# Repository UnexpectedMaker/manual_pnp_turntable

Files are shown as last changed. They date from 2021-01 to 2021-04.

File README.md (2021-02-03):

# Manual PnP Turntable V3

This Manual PnP Turntable is the latest version of my components storage & assembly turntable I initially designed way back in 2019!

I've been asked for the design files many times since I first showed it off in one of my videos, but the V2 version was just a terrible design from a construction stand point, and I always promised I'd release a newer version, and well, this is it!

## BETTER LATE THAN NEVER!

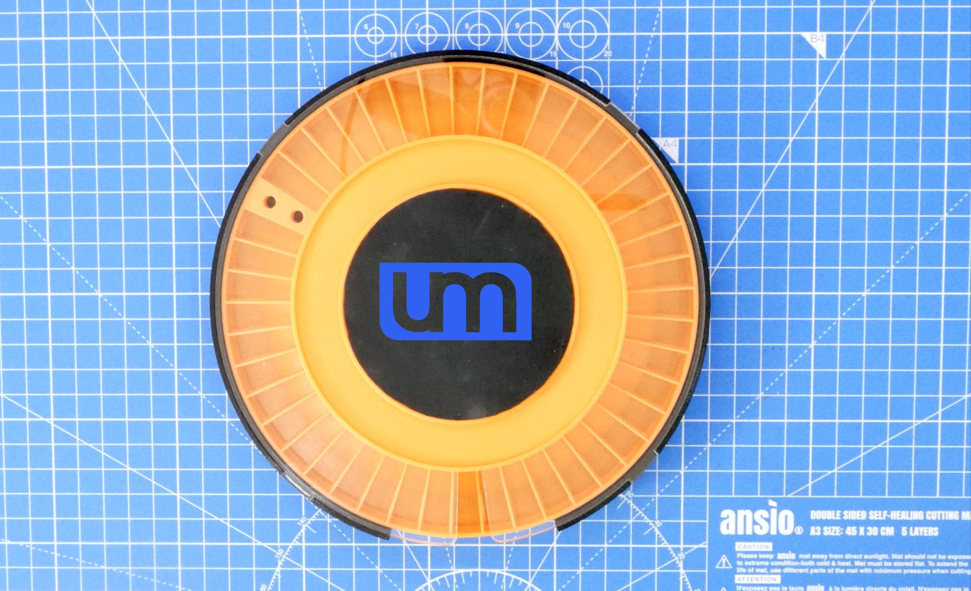
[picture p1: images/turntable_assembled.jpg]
Manual PnP Turntable V2


# Printing The 3D Pieces

### NOTE: The main parts for this turntable require a 3D printer with a print bed of 200mm x 200mm or larger.

There are 3 main 3d printed pieces that make up the turntable, plus some extras.

## turntable_V3_base.stl

- Layer height: 0.2mm
- Brim: Yes
- Supports: None

## turntable_V3_component_tray.stl

- Layer height: 0.2mm
- Brim: Yes
- Supports: Yes, from build plate + bridging

## turntable_V3_assembly_tray.stl

- Layer height: 0.2mm
- Brim: No
- Supports: Yes, from build plate + bridging

## The rest of the files

- Layer height: 0.2mm
- Brim: No
- Supports: None

# Laser cutting or printing the component cover

The component tray cover file is turntable_V3_cover_lasercut.dxf and should be cut out of 3mm thick acrylic, preferably clear, but frosted could also look good. Something transparent so you can see the components and labels inside.

If you can't get access to a laser cutter, you can 3d print the cover by printing turntable_V3_cover_3dprint.stl

# Bearings

These are the bearings I use on the turntable:

6805N Nylon (25x37x6mm)
https://s.click.aliexpress.com/e/_Am2lJV

Smaller (8x22x7mm)
https://s.click.aliexpress.com/e/_9AlN6x

# Assembly Instructions...

I made a video about the turntable and how to assemble it:
(http://www.youtube.com/watch?v=scHSrFdWn5k "Assembly Instructions")

I hope you enjoy making and using this design. If you do, please contact me and let me know you made one and maybe send me a pic!

Cheers :)

# Support Unexpected Maker

I love designing, making and releasing my projects as open source. I do it because I believe it’s important to share knowledge and give back to the community, like many have done before me. It helps us all learn and grow.

That said, a lot of time, effort and finances have gone into designing and releasing these files, so please consider supporting me by buying some of my products:

https://unexpectedmaker.com/shop

https://www.tindie.com/stores/seonr/

Or by becoming a Patron:

https://www.patreon.com/unexpectedmaker

# Join my discord server
https://discord.com/invite/xAHpApP

# Unexpected Maker
https://unexpectedmaker.com

http://youtube.com/unexpectedmaker

http://twitter.com/unexpectedmaker

https://www.facebook.com/unexpectedmaker/

https://www.instagram.com/unexpectedmaker/

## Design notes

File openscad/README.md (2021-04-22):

# Openscad designs for Manual PnP Turntable V3

This is parametric design for Manual PnP Turntable V3 with openscad files that should be easy to modify for various parameters (bearing height, diameter, parts thickness etc). 
As it is it should be fully compatible and other designs unless I made some mistakes.

# Diffeerences from original design

- turntable_base_7mm.stl 
 
New base for bearing 6805-ZZ 25x37x7mm which is cheaper on Amazon on US than original but it 1mm thicker. All other parts remain the same.

I do not like to loose a lot material for support so I created different design for parts tray. It consists of 2 parts A and B and they are glued together. 
Part B has 2 variants - with hole for bearing access and without one. Print only one part B you prefer. Part A stays the same.

- turntable_parts_tray_partA.stl
- turntable_parts_tray_partB_hole.stl
- rntable_parts_tray_partB_nohole.stl

Enjoy.

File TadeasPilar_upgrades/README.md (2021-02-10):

# Manual PNP turntable
## Improvements by [Tadeáš Pilař](https://github.com/TadeasPilar/)

This is my spin at improving the Manual PNP turntable by [Seon aka the Unexpected Maker](https://github.com/UnexpectedMaker)
Made to solve my personal needs in the limited time I had to play with this. Feel free to critisize, redo, or outright refuse my ideas :D

This is compilation of several unrelated changes to the original design. Each of them can be used separatly or all together.
List below lists all the improvments and parts you will have to reprint. Parts I don't mention are same as in the original design.
Images below this list.

They are:
  * Lock ring to hold the plexi in place
    No need to glue or tape the plexiglass. 
    You will need to print new [turntable base](stl/turntable_base.stl) and [lock ring](stl/turntable_lock_ring.stl).
    Held in by several M3x5 self-tapped machine screws(the flat head type). 
    There are holes for 7 screws, but I find 3 are enough.

  * Component tray with joined compartments
    Do you have bigger smd parts to store? No problem.
    Use [new component tray](stl/turntable_component_tray_joined_compartments.stl)  with several compartments joined together.
    Or [this one](stl/turntable_component_tray_joined_compartments_reverse.stl) with inner slopes reversed for some reason...
    Expect more wariants of this to appear in the future.
    
  * No ball bearings - no problem!!!
    [3D printable rings](stl/turntable_bearings.stl) to replace ball bearings.
    Not as smoothm, but definitely usable.
    Beware of limitations of plastic slip bearings. They will not last! But definitely good enough while you wait for real ballbearings to arrive.
    
  * Easy tape fill funnel
    [Funnel variant](stl/turntable_funnel_12x2mm_tape.stl) made for easy filling from tape. 
    Pull tape through(upside down), then using tweezers, loop cover tape back throug the lower hole.
    Now, just pull on the tape and watch your parts neatly pour to your selected compartment.
    WARNING!!! Pulling the cover tape through is real pain in the ass. Only realy worth it if you have lot of parts to get out of the tape. 

## Yay Images   

### New base and lock ring
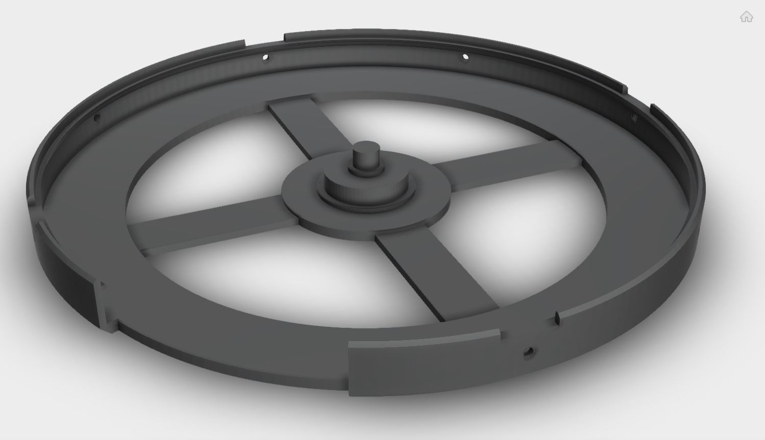
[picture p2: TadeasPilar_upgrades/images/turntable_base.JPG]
Base

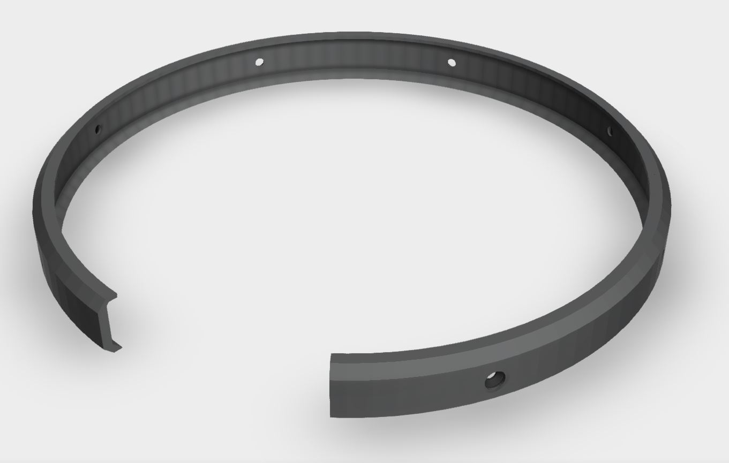
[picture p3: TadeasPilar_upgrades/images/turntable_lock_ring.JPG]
Lock ring


### Components tray with bigger compartments.
Choose your prefered slope direction.<br>
Normal:<br>
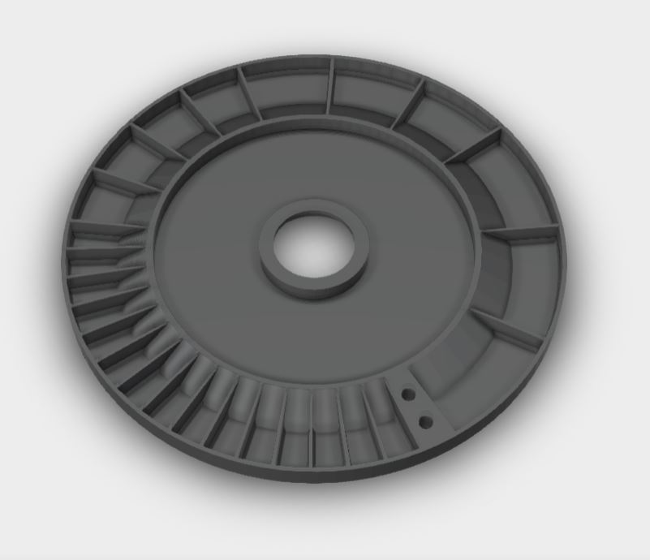
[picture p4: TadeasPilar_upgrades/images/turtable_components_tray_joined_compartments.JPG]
Components tray
<br>
Reversed:<br>
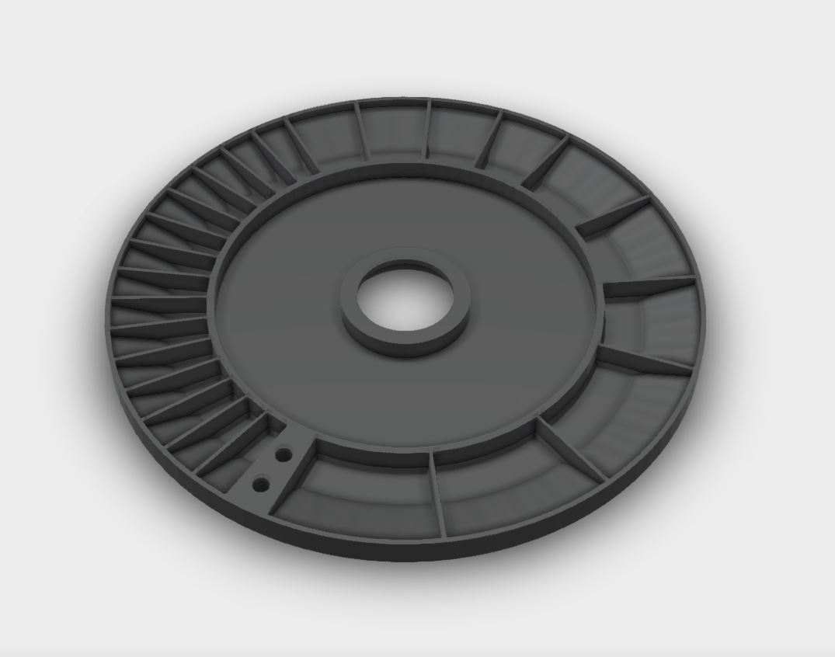
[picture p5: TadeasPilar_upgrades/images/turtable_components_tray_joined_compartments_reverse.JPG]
Components tray


### Plastic bearings
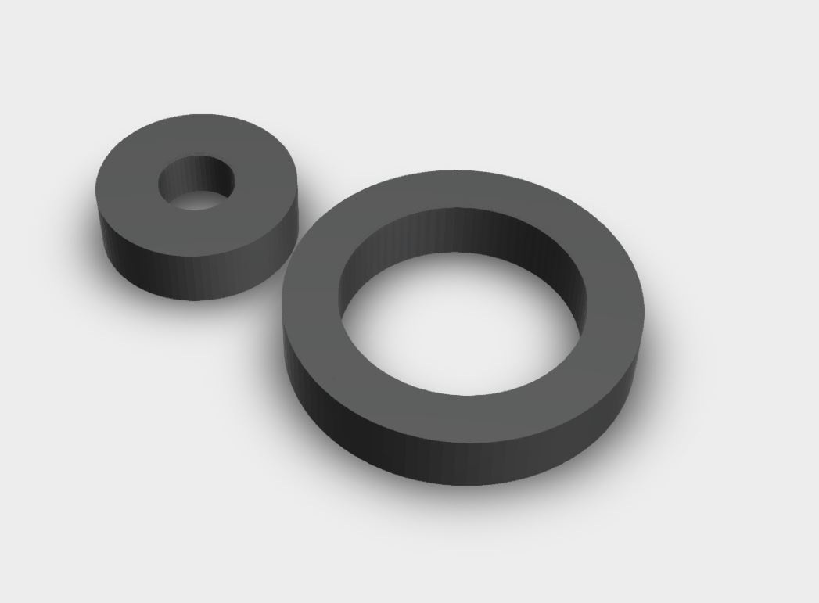
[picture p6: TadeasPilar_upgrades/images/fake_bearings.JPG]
Plastic bearings


## Easy fill funnel
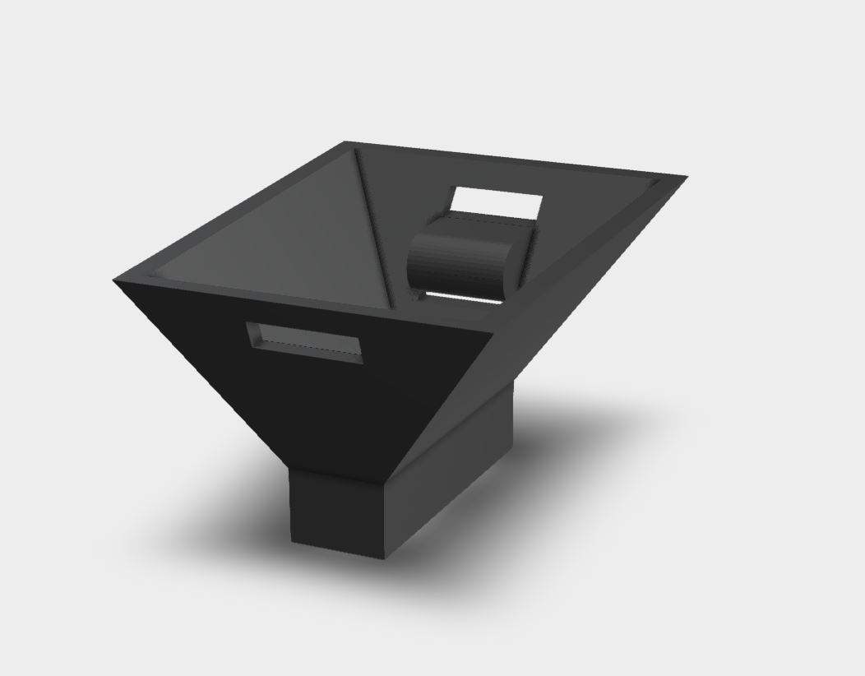
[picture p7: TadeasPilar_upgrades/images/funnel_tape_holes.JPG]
Funnel


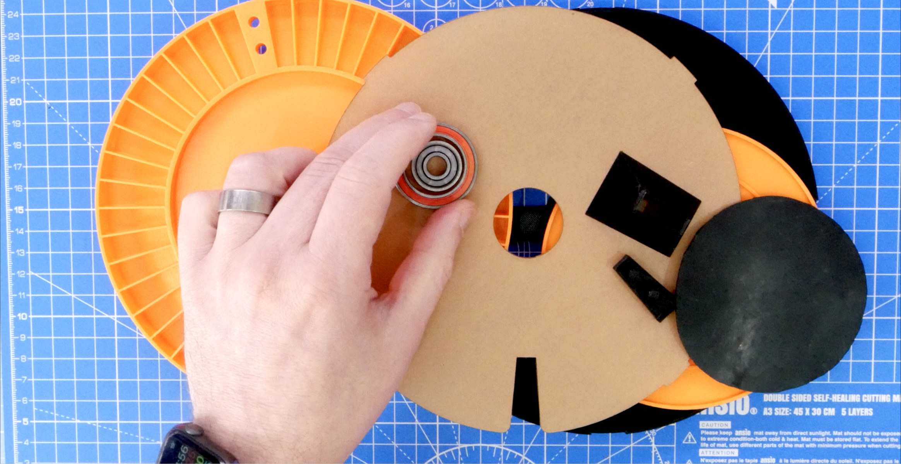
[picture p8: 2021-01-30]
images/turntable_pieces.jpg

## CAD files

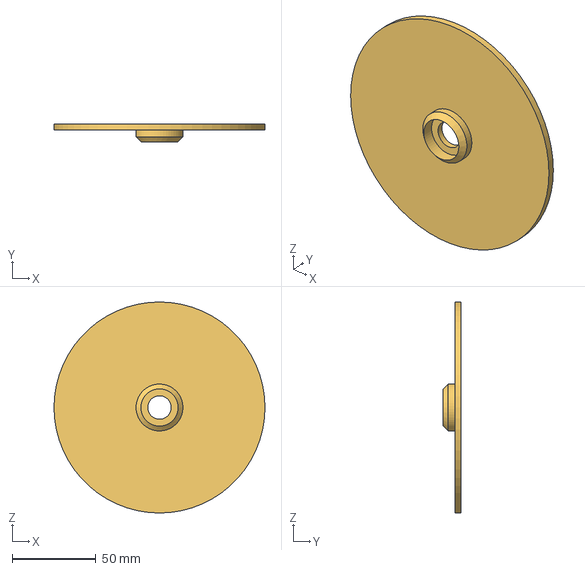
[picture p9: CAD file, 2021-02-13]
step/turntable_V3_assembly_tray.step
126.0 x 10.5 x 126.0 mm

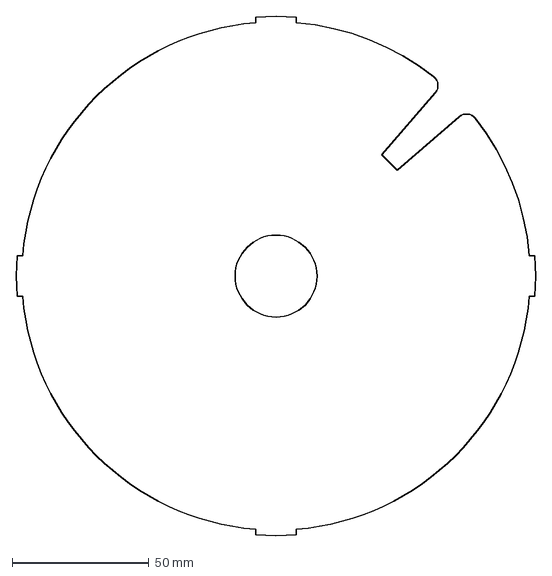
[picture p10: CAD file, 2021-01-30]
dxf/turntable_V3_cover_lasercut.dxf
190.2 x 190.2 mm

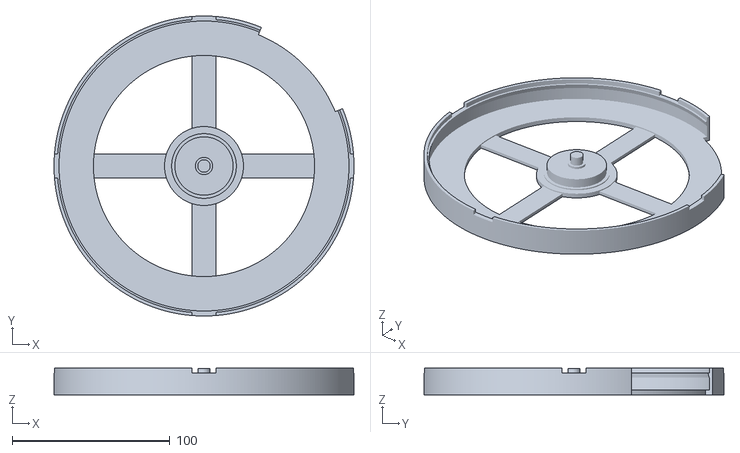
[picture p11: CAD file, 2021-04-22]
openscad/turntable_base_7mm.stl
190.0 x 190.0 x 17.0

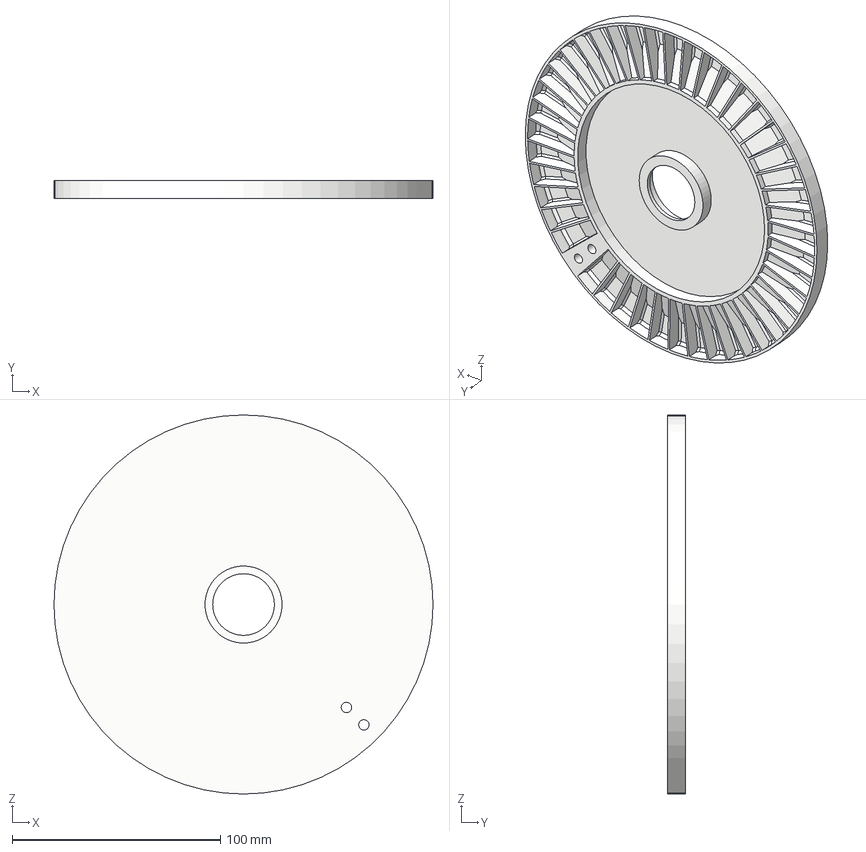
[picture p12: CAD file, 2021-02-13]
step/turntable_V3_component_tray.step
182.0 x 8.60 x 182.0 mm

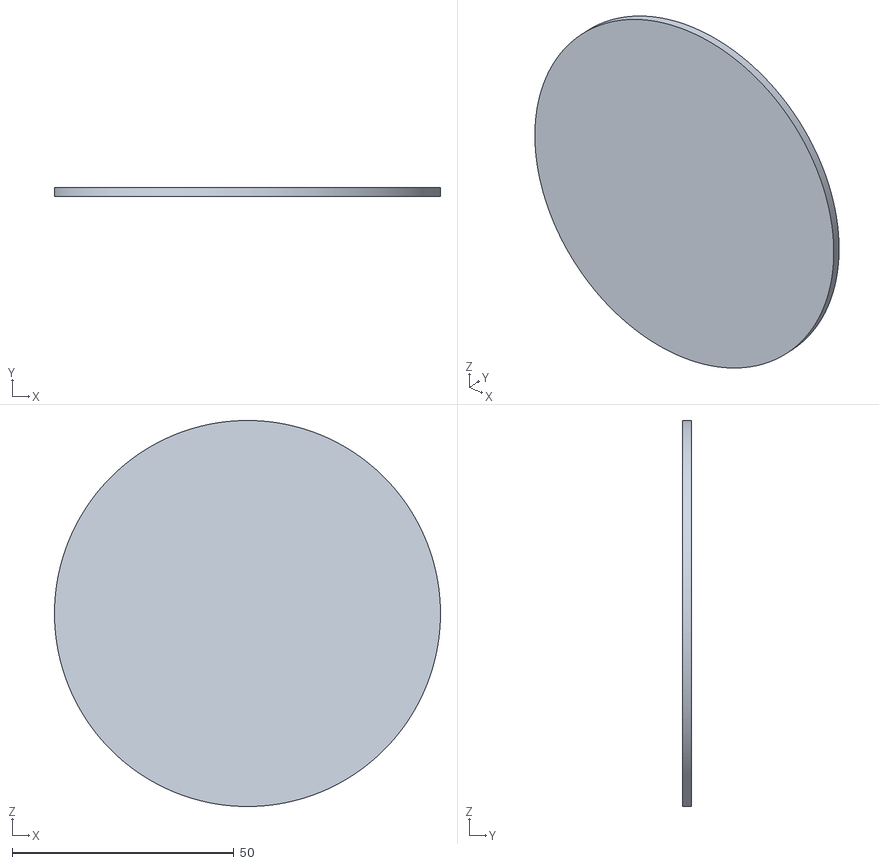
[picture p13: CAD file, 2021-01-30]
stl/turntable_V3_rubber_cutter.stl
87.0 x 2.00 x 87.0

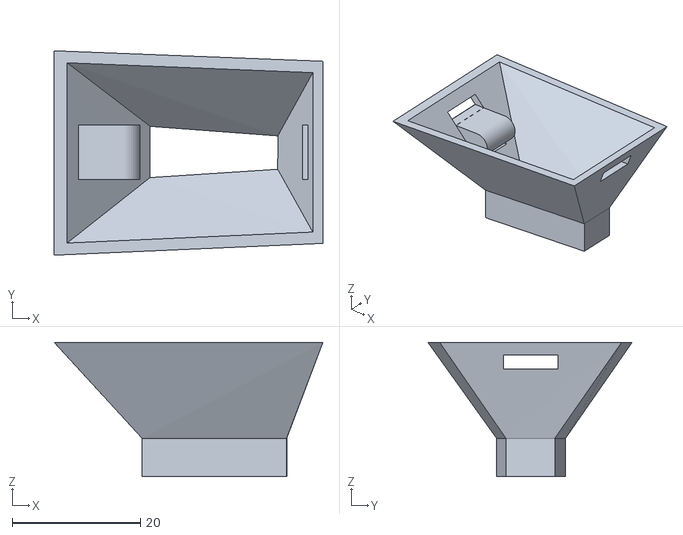
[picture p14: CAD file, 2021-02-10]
TadeasPilar_upgrades/stl/turntable_funnel_12x2mm_tape.stl
42.0 x 31.9 x 21.0

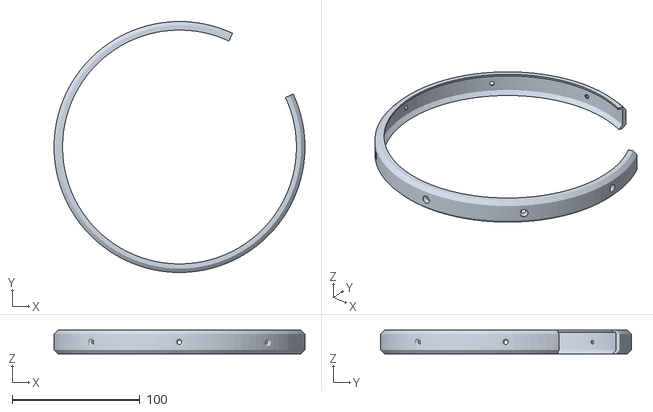
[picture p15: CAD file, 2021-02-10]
TadeasPilar_upgrades/stl/turntable_lock_ring.stl
196.4 x 196.4 x 18.5

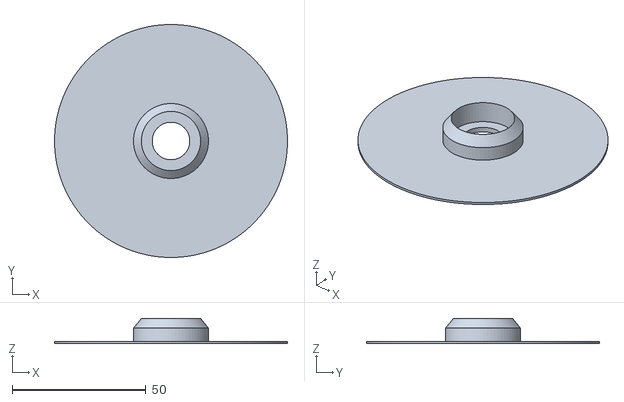
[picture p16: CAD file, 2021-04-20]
openscad/turntable_parts_tray_partB_hole.stl
87.0 x 87.0 x 9.43

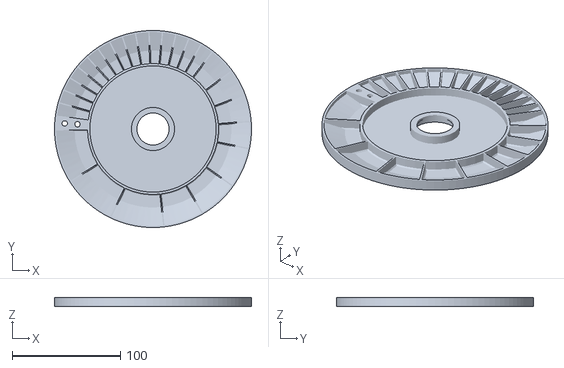
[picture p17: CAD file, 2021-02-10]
TadeasPilar_upgrades/stl/turntable_component_tray_joined_compartments_reverse.stl
182.0 x 182.0 x 8.60

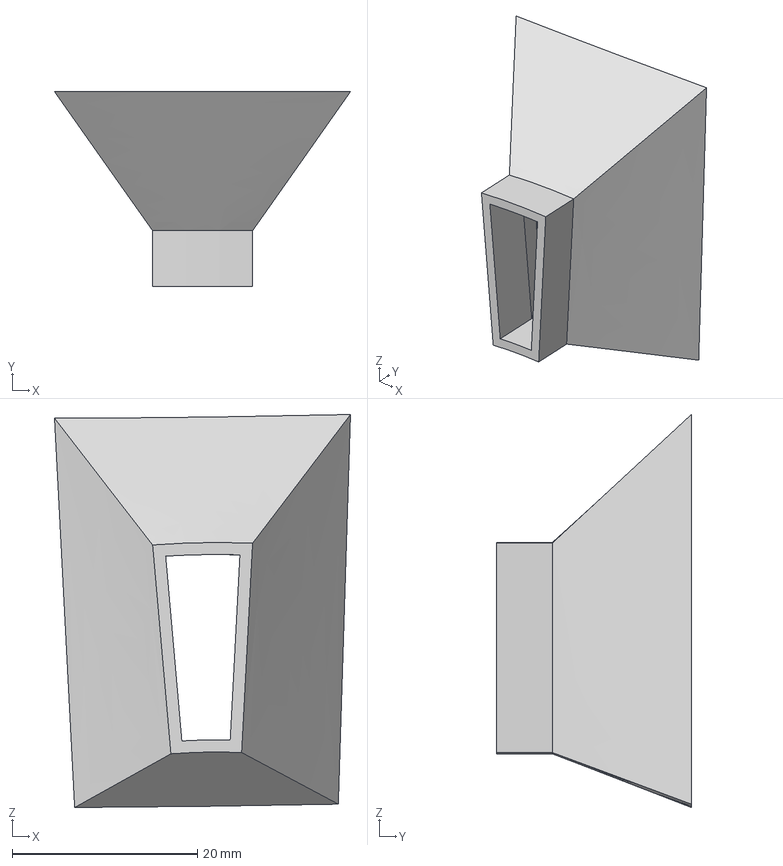
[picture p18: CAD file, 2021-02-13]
step/turntable_V3_funnel.step
31.9 x 21.0 x 42.4 mm

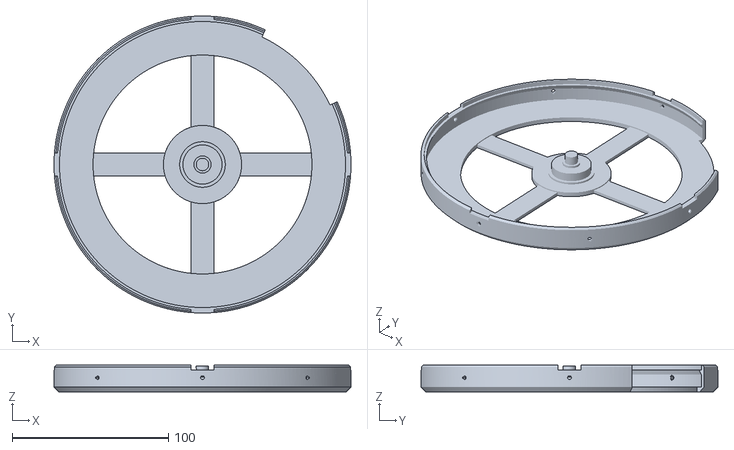
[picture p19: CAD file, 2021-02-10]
TadeasPilar_upgrades/stl/turntable_base.stl
190.0 x 190.0 x 17.0

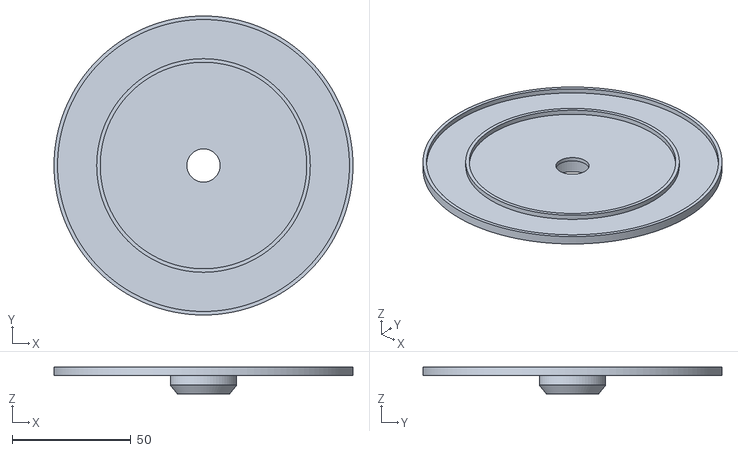
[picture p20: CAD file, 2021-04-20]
openscad/turntable_parts_tray_hole.stl
126.0 x 126.0 x 11.2

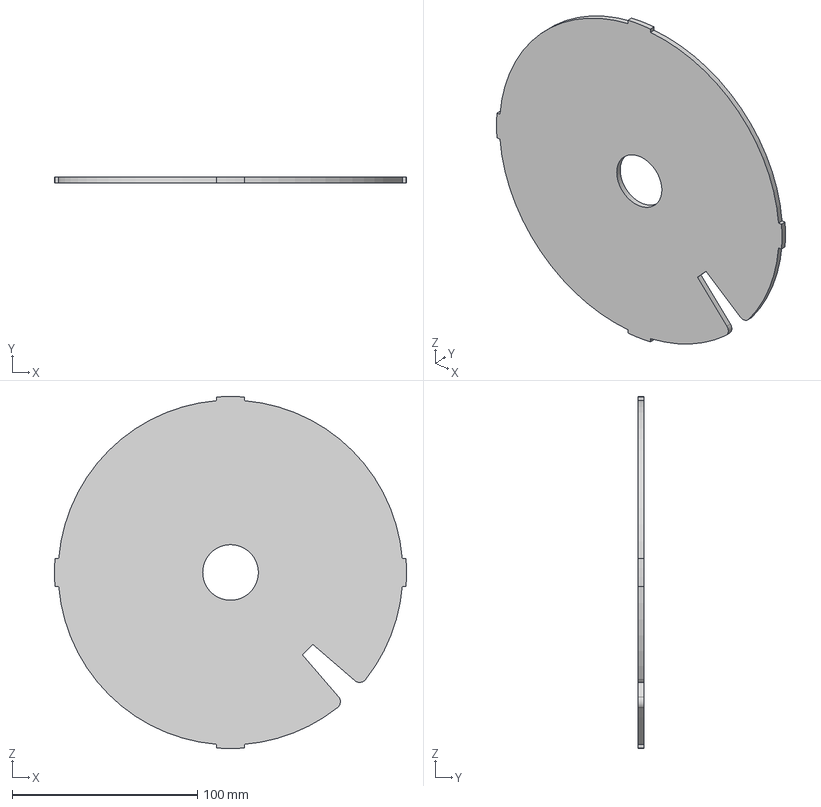
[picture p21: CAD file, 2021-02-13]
step/turntable_V3_cover_3dprint.step
189.9 x 3.00 x 189.9 mm

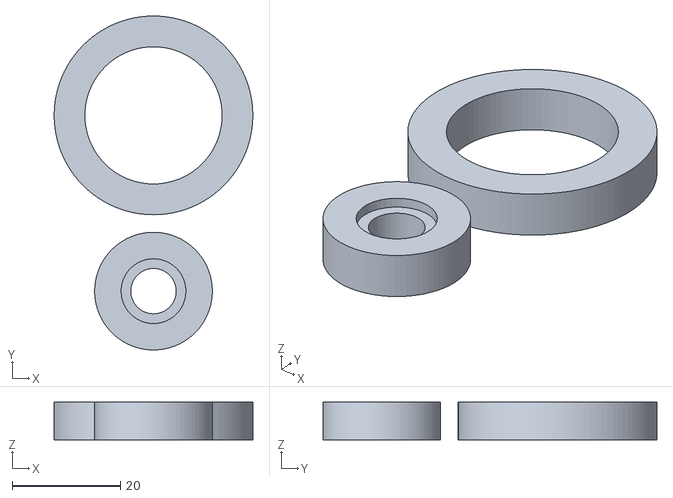
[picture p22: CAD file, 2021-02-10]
TadeasPilar_upgrades/stl/turntable_bearings.stl
36.8 x 61.8 x 7.00

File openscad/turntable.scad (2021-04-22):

tolerance = 0.05;

component_tray_dia = 182;
component_tray_height = 8.6;
component_tray_inner_idia = 39.8;
component_tray_inner_odia = 116.6;
component_tray_inner_thk = 2;
component_tray_hole_dia = 29.6;
component_tray_stopper_hole_dia=5;

component_pocket_idia = 121;
component_pocket_odia = 179;
component_pocket_length = 29;
component_pocket_depth = 8.1;
component_pocket_angle = 8;

component_bearing_idia = 25;
component_bearing_odia = 37;
component_bearing_height = 6;

parts_outer_dia = 126;
parts_inner_dia = 90;
parts_border = 3;
parts_hole_dia = 14;
parts_thk = 1.6;
parts_border_thk = 2;
parts_bearing_holder_dia = 28;
parts_bearing_holder_height = 4;
parts_bearing_holder_thk = 3.20;

part_bearing_idia = 8;
part_bearing_odia = 22;
part_bearing_height = 7;

base_height = 17;
base_outer_dia = component_tray_dia + 8;
base_outerloop_odia = component_tray_dia + 4;
base_outerloop_idia = base_outerloop_odia - 46;
base_sector_angle = 45;

cover_something_width = 15;
cover_thk = 3;

base_innerloop_odia = 50;
base_outerloop_thk = 3;
base_innerloop_thk = base_outerloop_thk;

module sector(h, d, a1, a2) {
    if (a2 - a1 > 180) {
        difference() {
            cylinder(h=h, d=d,$fn=256);
            translate([0,0,-0.5]) sector(h+1, d+1, a2-360, a1); 
        }
    } else {
        difference() {
            cylinder(h=h, d=d,$fn=256);
            rotate([0,0,a1]) translate([-d/2, -d/2, -0.5])
                cube([d, d/2, h+1]);
            rotate([0,0,a2]) translate([-d/2, 0, -0.5])
                cube([d, d/2, h+1]);
        }
    }
}    

module base() {
    difference() {
        union() {
            cylinder( d=base_innerloop_odia, h=base_innerloop_thk, $fn=128 );
            for( a=[0:90:360] )
                rotate([0,0,a] )
                    translate([0,base_outerloop_idia/4 + base_innerloop_odia/4,1.1])
                        cube( size=[15,(base_outerloop_idia - base_innerloop_odia)/2 + 4,2.2],center=true );

            difference() {
                cylinder( d=base_outerloop_odia+1, h=base_innerloop_thk, $fn=256 );
                translate([0,0,-1])
                cylinder( d=base_outerloop_idia, h=base_innerloop_thk+2, $fn=256 );
            }

            difference() {
                cylinder( d=base_outer_dia, h=base_height, $fn=256 );
                translate([0,0,base_height-cover_thk])
                   cylinder( d=base_outerloop_odia, h=cover_thk+2, $fn=256 );
                translate([0,0,base_height-cover_thk-4])
                    cylinder( d2=component_tray_dia+1,d1=base_outerloop_odia,h=5,$fn=256 );
                translate([0,0,-1])
                   cylinder( d=base_outerloop_odia, h=base_height-cover_thk-2, $fn=256 );
                for( a=[0:90:360] )
                    rotate([0,0,a] )
                        translate([0,base_outer_dia/4+base_outerloop_odia/4,base_height-cover_thk/2+1])
                        cube( size=[cover_something_width,(base_outer_dia-base_outerloop_odia)/2+4,cover_thk+2],center=true );
            }
            
            cylinder( d=component_bearing_odia+4,h=base_innerloop_thk+7.8-component_bearing_height,$fn=64 );
            cylinder( d=component_bearing_odia-2*tolerance,h=base_innerloop_thk+6.6,$fn=128 );
            cylinder( d=part_bearing_idia+3,h=base_innerloop_thk+15-part_bearing_height,$fn=64 );
            cylinder( d=part_bearing_idia-2*tolerance,h=base_innerloop_thk+13.6,$fn=64 );
        }

        difference() {
            translate([0,0,-1])
            sector( base_height+2,    base_outer_dia+4,(90-base_sector_angle)/2,(90+base_sector_angle)/2);
            translate([0,0,-2])
            sector( base_height+4,    base_outer_dia-10,(90-base_sector_angle)/2-10,(90+base_sector_angle)/2+10);
        }
    }
}

module component_pocket()
{
    hull() {
        difference() {
            translate( [0,(component_pocket_length-component_pocket_odia)/2,component_pocket_depth-4.2] )
                cylinder( d=component_pocket_odia,h=4.2,$fn=256 );
            translate( [0,(-component_pocket_idia-component_pocket_length)/2,component_pocket_depth-5.2] )
                cylinder( d=component_pocket_idia,h=6.2,$fn=256 );
            for( i=[-1,1] ) 
                translate([i*component_pocket_odia/2,-component_pocket_odia/2,0]) 
                    rotate( [0,0,-i*4] )
                        cube( size=[component_pocket_odia, component_pocket_odia*2, component_pocket_depth*2 + 4], center=true );
            
        }
        difference() {
            translate( [0,7,0.5] )
                cube( size=[20,10.7,1],center=true );
            for( i=[-1,1] ) 
                translate([i*component_pocket_odia/2,-component_pocket_odia/2,0]) 
                    rotate( [0,0,-i*3] )
                        cube( size=[component_pocket_odia, component_pocket_odia*2, 2*(component_pocket_depth-4.2 )], center=true );
        }
    }
}

module component_tray()
{
    difference() {
        cylinder( d=component_tray_dia, h=component_tray_height, $fn=256 );
        difference() {
            translate( [0,0,component_tray_inner_thk] )
                cylinder( d=component_tray_inner_odia, h=component_tray_height, $fn=128 );
            cylinder( d=component_tray_inner_idia, h=component_tray_height+component_tray_inner_thk+2, $fn=128 );
        }
        translate( [0,0,-1] )
            cylinder( d=component_tray_hole_dia, h=component_tray_height+2, $fn=64 );
        translate( [0,0,-2] )
            cylinder( d=component_bearing_odia+2*tolerance, h=component_tray_height, $fn=64 );
        translate( [0,70,-1] )
            cylinder( d=component_tray_stopper_hole_dia, h=component_tray_height+2, $fn=32 );
        translate( [0,81.7,-1] )
            cylinder( d=component_tray_stopper_hole_dia, h=component_tray_height+2, $fn=32 );
        for( a=[10:10:350] ) 
            rotate( [0,0,a] )
                translate( [0,(component_pocket_idia+component_pocket_odia)/4,component_tray_inner_thk] )
                    component_pocket();
            
        
    }
}

/*
     part 1 - single parts tray
          2 - two modules maint part
          3 - two modeles bearing part
*/

module parts_tray(hole=1,part=1)
{
    difference() {
        union() {
            if( part != 3 )
                cylinder( d=parts_outer_dia, h=parts_thk+parts_border_thk,$fn=128 );
            else 
                cylinder( d=parts_inner_dia-parts_border, h=parts_thk/2,$fn=128 );
                
            if( part != 2 ) {
                holder_height = parts_bearing_holder_height + ( part == 3 ? parts_border_thk / 2:0);
                translate( [0,0,-holder_height] )
                    cylinder( d=parts_bearing_holder_dia, h=holder_height,$fn=64 );
                translate( [0,0,-holder_height-4] )
                    cylinder( d2=parts_bearing_holder_dia, d1=part_bearing_odia-0.5, h=4,$fn=64 );
            }
        }
        if( part == 2 )
            translate( [0,0,-1] )
                cylinder( d=parts_bearing_holder_dia, h=parts_thk+2,$fn=64 );
            
        difference() {
            translate( [0,0,parts_thk] )
                cylinder( d=parts_outer_dia-parts_border, h=parts_thk+parts_border_thk,$fn=128 );
            translate( [0,0,parts_thk-1] )
                cylinder( d=parts_inner_dia, h=parts_thk+parts_border_thk+2,$fn=128 );
        }
        translate( [0,0,parts_thk - (part!=2 ? 0 : parts_thk/2)] )
            cylinder( d=parts_inner_dia-parts_border, h=parts_thk+parts_border_thk,$fn=128 );
        if( hole ) 
            translate( [0,0,-2] )
                cylinder( d=parts_hole_dia, h=parts_thk+parts_border_thk+4,$fn=128 );

        if( part != 2 ) 
            translate( [0,0,-parts_bearing_holder_height-5-( part == 3 ? parts_border_thk / 2:0)] )
                cylinder( d=part_bearing_odia+2*tolerance, h=5+parts_bearing_holder_height,$fn=64 );

    }
}

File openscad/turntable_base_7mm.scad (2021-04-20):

include <turntable.scad>

component_bearing_height = 7;
base();

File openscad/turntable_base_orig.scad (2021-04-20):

include <turntable.scad>

base();

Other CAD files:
openscad/turntable_base_orig.stl
step/turntable_V3_base.step
openscad/turntable_component_tray.stl
openscad/turntable_parts_tray_partB_nohole.stl
openscad/turntable_component_tray.scad
TadeasPilar_upgrades/stl/turntable_component_tray_joined_compartments.stl
openscad/turntable_parts_tray_hole.scad
openscad/turntable_parts_tray_nohole.scad
openscad/turntable_parts_tray_nohole.stl
openscad/turntable_parts_tray_partA.scad
openscad/turntable_parts_tray_partA.stl
openscad/turntable_parts_tray_partB_hole.scad
openscad/turntable_parts_tray_partB_nohole.scad
step/turntable_V3_rotation_plug.step
stl/turntable_V3_assembly_tray.stl
stl/turntable_V3_base.stl
stl/turntable_V3_component_tray.stl
stl/turntable_V3_cover_3dprint.stl
stl/turntable_V3_funnel.stl
stl/turntable_V3_rotation_plug.stl

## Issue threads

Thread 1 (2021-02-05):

Is is possible to get cad files?

vitormhenrique, 2021-02-05:
This is an awesome design! thanks for sharing!
Would you mind sharing the cad designs for it (step files for example) ? (instead of the STL ones) there are a couple things that I think would be nice, and editing STL's are never too fun...

Thanks!

UnexpectedMaker, 2021-03-07:
Not suer if you noticed but I added STEP files a while ago :)

vitormhenrique, 2021-03-07:
I did! Thank you very much!

Closed 2021-03-07.

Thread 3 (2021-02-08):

Thin bottom component tray, maybe thicken it to 0.8mm?

Squantor, 2021-02-08:
I think the component tray has very thin bottom. When I slice the STL in cura it is only two layers. that is a bit on the thin side. Would it be an idea to make it a bit thicker so it is at least three or four layers? I print mostly in PETG and the white filament I have is a more translucent then really white. A few extra layers would help with the opacity, but this is a problem on my side.

Another thing I have noticed but not related to the STL's is that when I slice the component tray with cura, the tool path in cura differs from what is being printed! Really strange, but this is cura's problem. Cura shows the first layer begin printed as one big surface and then makes the component pockets, but in reality the first layer prints quite different with small component pockets and then printing the walls seperate.

Thanks for making this device public, I am printing everything in steps. Black base, white component tray and gray assembly tray. Just waiting for the bearings.

For these big flat prints, I am really glad I installed an ABL sensor on my printer.

rglory, 2021-04-19:
Actually it would be nice to make it 1mm thicker and on top of that it will work with  6805-ZZ bearing which is math cheaper on Amazon but 1mm thicker.

UnexpectedMaker, 2021-04-19:
> Actually it would be nice to make it 1mm thicker and on top of that it will work with 6805-ZZ bearing which is math cheaper on Amazon but 1mm thicker.

The STL files are available for those that want to modify the design to work with different thickness bearings. I chose these because I wanted the unit as low profile as possible.

rglory, 2021-04-19:
I understand. But cheapest bearing for 25x37x6mm I can find on amazon costs $11.49 ($5.75/Item)  while 25x37x7mm costs $14.97 ($1.50 / Item) - quite some difference for 1mm thickness difference.

UnexpectedMaker, 2021-04-19:
Ok, so you can buy the cheaper one and modify the STL file to suit. Or you can buy the bearings from Aliexpress and pay 1/3 of the price. Either way you have options :)

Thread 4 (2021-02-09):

Base for 4mm plexi?

taposk, 2021-02-09:
Hello!
Is it possible to get a version of the base for 4mm acrylic?
In France we mostly find 4mm plates and not 3mm...
Thanks!!

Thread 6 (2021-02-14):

Tolerances are a little tight

bjonesrock, 2021-02-14:
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

Hey I'm really excited to finish putting this together. I have to wait a month for the bearings. But I printed the parts and laser cut some 3mm acrylic. When I put the parts together I ended up having to file down the tabs on the laser cut acrylic for it to fit together. It would be great if the tolerances were a little looser to account for less than perfect 3D printers and laser cutters

Thanks!
-Ben

bjonesrock, 2021-02-16:
[pnp-3mm-acrylic-v2.zip](https://github.com/UnexpectedMaker/manual_pnp_turntable/files/5986199/pnp-3mm-acrylic-v2.zip)
I scaled down the outside part of the DXF slightly and it's a perfect fit when I cut it with my laser cutter now. I converted it to an SVG in inkscape. I'm attaching the file I used, feel free to use it in your project. Thanks!

Closed 2021-02-16.

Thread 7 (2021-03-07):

Tray scrapes on frame - not enough clearance on bearing

bjonesrock, 2021-03-07:
When the larger bearing is pressed flush into the tray it doesn't have enough clearance on the bottom to spin freely

I think the bottom lip for the large bearing needs to be taller

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

UnexpectedMaker, 2021-03-07:
Mine is pushed 100% as far as I can push it and I don't see that issue. Maybe just a printer tolerance thing?

bjonesrock, 2021-03-07:
It's possible, I had a lot of issues with the filament I used to print this. I don't know why I decided to use something other than Hatchbox.

I didn't buy the larger bearing from Aliexpress, I found an ebay seller that had the same specs:
https://www.ebay.com/itm/10pcs-6805RD-MR25376-61805-6805N-6805-RS-Ball-Bearing-25x37x6mm-HT2-BB51-GCR15/283611747473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

It's possible the inner ring on the bearing you have is taller than mine

I'm going to try printing some shims at different heights and see is that fixes it
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

If that fixes it I'll attach the STL file

bjonesrock, 2021-03-07:
Using a shim with a height of 0.5mm mostly fixed it for me. I think my tray and/or my frame might be slightly warped which is causing the tray to rub on both the acrylic and the frame.

Attached is the STL file. I tried a bunch of different heights. If someone else has this issue later and 0.5mm isn't the right height for you, just scale the STL file on the Z axis to the size you need.

[0.5mm-shim.stl.zip](https://github.com/UnexpectedMaker/manual_pnp_turntable/files/6096545/0.5mm-shim.stl.zip)

Closed 2021-03-07.

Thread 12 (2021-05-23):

License clarification

darigovresearch, 2021-05-23:
This is a great project and thanks for releasing it!

Would be helpful to know what kind of license this project is under CC0 (like the [infidel filament diameter sensor](https://github.com/drspangle/infidel-sensor)), CERN (like the [openflexure 3D printed microscope](https://gitlab.com/openflexure/openflexure-microscope) or TAPR (like the [Glia otoscope](https://github.com/GliaX/Otoscope)) just to name a few. This may encourage people to build on top of your work and also potentially contribute back to the project as well.

Also you mention that you won't be selling it as a product but perhaps someone from the community may wish to do so, having clarification on the license and if it can be used for commercial use would be helpful to know.

Could you please advise?

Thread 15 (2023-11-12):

Idea for clipping lid

Bazmundi, 2023-11-12:
So firstly thanks for releasing this design, it's gold!

Not forgetting good job doing this in OpenSCAD.

Second, I have an idea for clipping the lid down.

So far it looks like this (just a hack at the moment):

```

/* new parameters will need be added to go further */
cover_something_width = 2;
cover_thk = 10;

module base() {
    difference() {
        union() {
            cylinder( d=base_innerloop_odia, h=base_innerloop_thk, $fn=128 );
            for( a=[0:90:360] )
                rotate([0,0,a] )
                    translate([0,base_outerloop_idia/4 + base_innerloop_odia/4,1.1])
                        cube( size=[15,(base_outerloop_idia - base_innerloop_odia)/2 + 4,2.2],center=true );

            difference() {
                cylinder( d=base_outerloop_odia+1, h=base_innerloop_thk, $fn=256 );
                translate([0,0,-1])
                cylinder( d=base_outerloop_idia, h=base_innerloop_thk+2, $fn=256 );
            }

            difference() {
                cylinder( d=base_outer_dia, h=base_height, $fn=256 );
                translate([0,0,base_height-cover_thk])
                   cylinder( d=base_outerloop_odia, h=cover_thk+2, $fn=256 );
                translate([0,0,base_height-cover_thk-4])
                    cylinder( d2=component_tray_dia+1,d1=base_outerloop_odia,h=5,$fn=256 );
                translate([0,0,-1])
                   cylinder( d=base_outerloop_odia, h=base_height-cover_thk-2, $fn=256 );
        
                /* here is the main hack */
                for( a=[0:90:360] ) {
                    rotate([0,0,a-5] )
                        translate([0,base_outer_dia/4+base_outerloop_odia/4,base_height-cover_thk/2+1])
                        cube( size=[cover_something_width,(base_outer_dia-base_outerloop_odia)/2+4,cover_thk+2],center=true );
                    rotate([0,0,a+5] )
                        translate([0,base_outer_dia/4+base_outerloop_odia/4,base_height-cover_thk/2+1])
                        cube( size=[cover_something_width,(base_outer_dia-base_outerloop_odia)/2+4,cover_thk+2],center=true );
                }
            }
    
            cylinder( d=component_bearing_odia+4,h=base_innerloop_thk+7.8-component_bearing_height,$fn=64 );
            cylinder( d=component_bearing_odia-2*tolerance,h=base_innerloop_thk+6.6,$fn=128 );
            cylinder( d=part_bearing_idia+3,h=base_innerloop_thk+15-part_bearing_height,$fn=64 );
            cylinder( d=part_bearing_idia-2*tolerance,h=base_innerloop_thk+13.6,$fn=64 );
        }

        difference() {
            translate([0,0,-1])
            sector( base_height+2,    base_outer_dia+4,(90-base_sector_angle)/2,(90+base_sector_angle)/2);
            translate([0,0,-2])
            sector( base_height+4,    base_outer_dia-10,(90-base_sector_angle)/2-10,(90+base_sector_angle)/2+10);
        }
    }
}
```

It turns out as the outer radius is 180mm, adding or subtracting 5 degrees coincidently gives a cord length of 15mm, centred on the tabs on the lid.

So, next steps are to add a thicker rim where the lid sits and a v-groove.  The tabs on the lid will then need be bevelled.  So 3D print would solve that readily, but it will take a little filing when laser cutting clear perspex etc.

The idea to have the flexture clip hold the lid on.  Probably wants finger nail tabs to help flex the clip etc.

I'll get back to you once I've prototyped this idea.   Unless you want to take the idea and run with?

Bazmundi, 2023-11-12:
Yeah so I ended up with a triangular notch, with ...

```
include <turntable.scad>
sqDia = 3;
sqRad = sqDia/2;

module notch() {
    intersection() {

        for(a = [0:90:360])
            sector(sqDia,base_outerloop_odia+sqDia,a-4.6,a+4.6);

        union(){
            cylinder(sqRad,d1=base_outerloop_odia,d2=base_outerloop_odia+sqRad,$fn=256);
            translate ([0,0,sqRad]) cylinder(sqRad,d1=base_outerloop_odia+sqRad,d2=base_outerloop_odia,$fn=256);
        }
    }
}
```
... and then ...

```
include <turntable.scad>
include <notch.scad>

component_bearing_height = 7;

difference () {
    base();
    translate([0,0,base_height-sqDia]) notch();
}
```
Works a hoot ...
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

Bazmundi, 2023-11-12:
Okay, you got me.  The module notch() needs to be:

```
include <turntable.scad>
sqDia = 3;
sqRad = sqDia/2;

module notch() {
    intersection() {

        difference () {
            for(a = [0:90:360])
                sector(sqDia,base_outerloop_odia+sqDia,a-4.6,a+4.6);
            cylinder( d=base_innerloop_odia, h=base_innerloop_thk, $fn=128 );
        }

        union(){
            cylinder(sqRad,d1=base_outerloop_odia,d2=base_outerloop_odia+sqRad,$fn=256);
            translate ([0,0,sqRad]) cylinder(sqRad,d1=base_outerloop_odia+sqRad,d2=base_outerloop_odia,$fn=256);
        }
    }
}
```

So as not to notch the pillar in the centre.

Bazmundi, 2023-11-12:
Yep, my bad.

```
cover_something_width = 1;
cover_thk = 3;
slot = 10;

module base() {
    union() {

        // add a thicker rim to make room for notch
        for(a = [0:90:360])
            translate([0,0,13])
               difference () {
                   sector(4,base_outerloop_odia+8,a-4.6,a+4.6);
                   sector(4,base_outerloop_odia+4,a-4.6,a+4.6);
               }

        // add a finger notch to assist in inserting the lid
        for(a = [0:90:360])
            translate([0,0,17])
               difference () {
                   sector(2,base_outerloop_odia+8,a-4.6,a+4.6);
                   sector(2,base_outerloop_odia+6,a-4.6,a+4.6);
               }

        difference() {
            union() {
                cylinder( d=base_innerloop_odia, h=base_innerloop_thk, $fn=128 );
                for( a=[0:90:360] )
                    rotate([0,0,a] )
                        translate([0,base_outerloop_idia/4 + base_innerloop_odia/4,1.1])
                            cube( size=[15,(base_outerloop_idia - base_innerloop_odia)/2 + 4,2.2],center=true );

                difference() {
                    cylinder( d=base_outerloop_odia+1, h=base_innerloop_thk, $fn=256 );
                    translate([0,0,-1])
                    cylinder( d=base_outerloop_idia, h=base_innerloop_thk+2, $fn=256 );
                }

                difference() {
                    cylinder( d=base_outer_dia, h=base_height, $fn=256 );
                    translate([0,0,base_height-cover_thk])
                       cylinder( d=base_outerloop_odia, h=cover_thk+2, $fn=256 );
                    translate([0,0,base_height-cover_thk-4])
                        cylinder( d2=component_tray_dia+1,d1=base_outerloop_odia,h=5,$fn=256 );
                    translate([0,0,-1])
                       cylinder( d=base_outerloop_odia, h=base_height-cover_thk-2, $fn=256 );
            
                    // the hack
                    for( a=[0:90:360] ) {
                        rotate([0,0,a-4.9] )
                            translate([0,base_outer_dia/4+base_outerloop_odia/4,base_height-slot/2+1])
                            cube( size=[cover_something_width,(base_outer_dia-base_outerloop_odia)/2+4,slot+2],center=true );
                        rotate([0,0,a+4.9] )
                            translate([0,base_outer_dia/4+base_outerloop_odia/4,base_height-slot/2+1])
                            cube( size=[cover_something_width,(base_outer_dia-base_outerloop_odia)/2+4,slot+2],center=true );
                    }
                }
        
                cylinder( d=component_bearing_odia+4,h=base_innerloop_thk+7.8-component_bearing_height,$fn=64 );
                cylinder( d=component_bearing_odia-2*tolerance,h=base_innerloop_thk+6.6,$fn=128 );
                cylinder( d=part_bearing_idia+3,h=base_innerloop_thk+15-part_bearing_height,$fn=64 );
                cylinder( d=part_bearing_idia-2*tolerance,h=base_innerloop_thk+13.6,$fn=64 );
            }

            difference() {
                translate([0,0,-1])
                sector( base_height+2,    base_outer_dia+4,(90-base_sector_angle)/2,(90+base_sector_angle)/2);
                translate([0,0,-2])
                sector( base_height+4,    base_outer_dia-10,(90-base_sector_angle)/2-10,(90+base_sector_angle)/2+10);
            }
        }
    }
}
```
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

Bazmundi, 2023-11-12:
Played a little and got a final draft that won't need supports.

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

Bazmundi, 2023-11-18:
Nope.  Probably as expected. The clips are too stiff and break off.  But, it occured to use the notch as a catch, and rotate the top into that from a slot, hence the solution at [thingiverse](https://www.thingiverse.com/thing:6310146).

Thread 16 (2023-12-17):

Error in component bearing post dia

Bazmundi, 2023-12-17:
component_bearing_idia is never used.  Line 95 seems to be the problem.

WAS

```
 94           cylinder( d=component_bearing_odia+4,h=base_innerloop_thk+7.8-component_bearing_height,$fn=64 );
 95           cylinder( d=component_bearing_odia-2*tolerance,h=base_innerloop_thk+6.6,$fn=128 );

```
IS

```
 94           cylinder( d=component_bearing_odia+4,h=base_innerloop_thk+7.8-component_bearing_height,$fn=64 );
 95           cylinder( d=component_bearing_idia-2*tolerance,h=base_innerloop_thk+6.6,$fn=128 );

```

A little poking around and my find validates https://github.com/UnexpectedMaker/manual_pnp_turntable/pull/11/files per rglory

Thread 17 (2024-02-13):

dxf for lasercutting is garbled up and has a lot of double lines which causes the slot to be not as smooth as it can be. Here is a fix

DrBabbage, 2024-02-13:
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

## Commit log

2021-01-30 Update README.md
    Added a note about the minimum print bed requirements for printing the 3 main parts.
2021-02-13 Added .step files to make it easier to modify the parts
    [turntable_V3_assembly_tray.step, turntable_V3_base.step, turntable_V3_component_tray.step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]
2021-04-20 Added parametric models using openscad
    [turntable.scad, turntable_base_7mm.scad, turntable_base_7mm.stl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]
2021-04-22 Fixed mistake with base bearing dia for components
    [turntable.scad, turntable_base_7mm.stl, turntable_base_orig.stl]
